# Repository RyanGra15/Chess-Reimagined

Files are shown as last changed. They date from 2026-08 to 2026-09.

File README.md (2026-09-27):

# Chess-Reimagined

An electronic chess board, that you can play (and lose) against 

## Features

* 64 Hall effect sensors to detect the position of the chess pieces
* LEDs matrix to indicate moves
* 0.96 inch OLED screen
* 3D printed board housing

## How It Works

The board uses Hall effect sensors underneath each square to detect whether a chess piece is present. Each chess piece will have a magnet embedded into its base, allowing the sensor underneath it to detect that a piece is present. Then, the software will take this, and represent it as a 64 bit string, with each bit signifying if there is a piece on the corresponding square. 

By backtracking through prior positions, all the way to the starting position, the ESP32 will be able to determine where each piece is. Then over Wifi, it will call the Stockfish API, get the best move, convert it back to the 64 bit string, and send it back to the Arduino. 

The Arduino will then control the LEDs underneath the board. The two squares involved in the move will light up, showing the player which piece to move and where to move it.

## Electronics

I am using multiplexing-esque approach for both the Hall effect sensors and the LEDs. By feeding 5V to a specified row, and making a specified column GND, I can choose to give power to a specific part. This allows me to control many signals without needing a separate connection for every single component. This keeps the circuit relatively simple and reduces the number of connections needed.

The main electronics are:

* Arduino Mega 2560
* ESP32
* Hall effect sensors
* LEDs
* S8550 PNP transistors
* Resistors
* Magnets
* Wires

The PCB is shown below, along with the schematic and routing diagrams: 













## CAD Model

The board housing will be 3D printed using PLA+. I chose PLA+ because it is cost efficient and is available in many different colors. The board will use a light grey and cold white colour scheme. 





The squares on the chess board have a hole in which the LED can be slotted into, along with a separate inset, wherein a extremely weak magnet can be placed, so that the chess pieces do not repel or attract each other, and instead they attract to the magnets embedded in the base of each square. This also has the added upside that you can flip the board upside down (if that is more your style ;)). See image below:



The chess pieces are also designed digitally and 3D printed, with some inspiration taken from previous chess related projects. 



The different parts will be attached together using hopes, dreams, and a lot of super glue.

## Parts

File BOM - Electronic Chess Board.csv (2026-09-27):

Item Name | Qty | Price (total) (EUR) | Price (total) (USD) | Item link | Notes
A3144EUA-T-JSM | 64 | € 6.96 | $8.07 | A3144EUA-T-JSM | Switches (Solid State) | JSMSEMI | LCSC | Must order a multiple of 5
5mm White Flat Top LED | 64 | € 6.04 | $7.01 | Amazon.com: CHANZON 100 pcs 5mm White Flat Top LED Diode Lights (DC 3V 20mA) | (Clear Transparent Lens) Bright Lighting Bulb Lamps Electronics Components Indicator Light Emitting Diodes DIY PCB Arduino : Industrial & Scientific | Preferably flat head LED
S8550 Transistor | 16 | € 1.32 | $1.53 | S8550 | Single Bipolar Transistors | JSMSEMI | LCSC | Must order a multiple of 100
20pcs 40P 2.54mm Pitch Single Row Pin Header Strip | 1 | € 4.74 | $5.50 | HiLetgo 20pcs 40P 2.54mm Pitch Single Row Pin Header Strip 40Pin 2.54mm Pitch: Amazon.com: Industrial & Scientific
MF1/4W-1K±1%-ST52 | 17 | € 0.76 | $0.88 | MF1/4W-1K±1%-ST52 | Through Hole Resistors | VO | LCSC | Must order a minimum quantity of 100
2.2K ohm, Resistance Tolerance: ± 5% tolerance, Material: Carbon Film | 1 | € 3.45 | $4.00 | California JOS 2.2K Ohm Carbon Film Single Fixed Resistor 1/2 W (0.5 Watts) 5% Tolerance (40 Pack): Amazon.com: Industrial & Scientific
HS96L03W2C03 | 1 | € 2.04 | $2.37 | HS96L03W2C03 | LCD, OLED, Graphic | HS | LCSC
MFR0W4F1002A50 | 50 | € 0.81 | $0.94 | MFR0W4F1002A50 | Through Hole Resistors | UNI-ROYAL | LCSC | Must order a minimum quantit of 50
Arduino Mega 2560 | 1 | € 16.99 | $19.71 | ARCELI Mega-2560-R3 Board, Mega-2560 Development Board with USB Cable Compatible with Arduino IDE : Amazon.nl: Electronics & Photo
ESP32 Devkit V1 | 1 | € 8.69 | $10.08 | JZK ESP-32S ESP32 Development Board 2.4GHz WiFi + Bluetooth Dual Mode Module Antenna Module with Ultra Low Power : Amazon.nl: Electronics & Photo
Solid Core 22 AWG Wire | 1 | € 19.99 | $23.19 | TUOFENG 22 awg solid wire - solid wire set - 6 different colored 9m spools, 22 gauge jumper wire - connection cable set : Amazon.nl: DIY & Tools
PLA Filament 1.75mm 1KG, White | 1 | € 13.99 | $16.23 | https://www.amazon.nl/-/en/eSUN-Filament-1-75mm-Printer-White/dp/B0CR1CS3K8
PLA Filament 1.75mm 1KG, Grey | 1 | € 13.99 | $16.23 | eSUN PLA Filament 1.75mm, PLA Base 3D Printer Filament 1kg White | Size accuracy +/- 0.02 mm. Smooth and fast printing without clogging. Premium material for FDM 3D printers. : Amazon.nl: Business, Industry & Science
USB C Power Recepticle | 1 | € 2.00 | $2.32 | 4 10pcs 2 pin type c extension cables transparent flat plug - Temu Netherlands
8mmx3mm Neodimium magnets | 32 | € 6.62 | $7.68 | refrigerator magnets 8x3mm magnet n35 magnetic round magnets - Temu Netherlands
1.5mm Self-Adhesive Magnets | 64 | € 1.53 | $1.77 | round self magnetic strip set made - Temu Netherlands
Total Price (USD): | $127.51

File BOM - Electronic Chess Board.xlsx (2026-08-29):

Item Name | Qty | Price (total) (EUR) | Price (total) (USD) | Item link | Notes
A3144EUA-T-JSM | 64 | €6.96 | $8.07 | A3144EUA-T-JSM | Switches (Solid State) | JSMSEMI | LCSC (https://www.lcsc.com/product-detail/C18188954.html) | Must order a multiple of 5
5mm White Flat Top LED | 64 | €6.04 | $7.01 | Amazon.com: CHANZON 100 pcs 5mm White Flat Top LED Diode Lights (DC 3V 20mA) | (Clear Transparent Lens) Bright Lighting Bulb Lamps Electronics Components Indicator Light Emitting Diodes DIY PCB Arduino : Industrial & Scientific (https://www.amazon.com/CHANZON-White-Flat-Diode-Lights/dp/B01BUVHSSE?cv_ct_cx=led%2Bkit%2Bflat%2Bhead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) | Preferably flat head LED
S8550 Transistor | 16 | €1.32 | $1.53 | S8550 | Single Bipolar Transistors | JSMSEMI | LCSC (https://www.lcsc.com/product-detail/C2931493.html) | Must order a multiple of 100
20pcs 40P 2.54mm Pitch Single Row Pin Header Strip | 1 | €4.74 | $5.50 | HiLetgo 20pcs 40P 2.54mm Pitch Single Row Pin Header Strip 40Pin 2.54mm Pitch: Amazon.com: Industrial & Scientific (https://www.amazon.com/HiLetgo-20pcs-2-54mm-Single-Header/dp/B07R5QDL8D)
MF1/4W-1K±1%-ST52 | 17 | €0.76 | $0.88 | MF1/4W-1K±1%-ST52 | Through Hole Resistors | VO | LCSC (https://www.lcsc.com/product-detail/C2903245.html?s_z=n_q_t_1k%2520resistor) | Must order a minimum quantity of 100
2.2K ohm, Resistance Tolerance: ± 5% tolerance, Material: Carbon Film | 1 | €3.45 | $4.00 | California JOS 2.2K Ohm Carbon Film Single Fixed Resistor 1/2 W (0.5 Watts) 5% Tolerance (40 Pack): Amazon.com: Industrial & Scientific (https://www.amazon.com/California-JOS-Carbon-Resistor-Tolerance/dp/B0BR699G4V)
HS96L03W2C03 | 1 | €2.04 | $2.37 | HS96L03W2C03 | LCD, OLED, Graphic | HS | LCSC (https://www.lcsc.com/product-detail/C5248080.html)
MFR0W4F1002A50 | 50 | €0.81 | $0.94 | MFR0W4F1002A50 | Through Hole Resistors | UNI-ROYAL | LCSC (https://www.lcsc.com/product-detail/C57436.html?s_z=n_q_t_10k%2520resistor) | Must order a minimum quantit of 50
Arduino Mega 2560 | 1 | €16.99 | $19.71 | ARCELI Mega-2560-R3 Board, Mega-2560 Development Board with USB Cable Compatible with Arduino IDE : Amazon.nl: Electronics & Photo (https://www.amazon.nl/-/en/ARCELI-Mega-2560-R3-Mega-2560-Development-Compatible/dp/B0CLVGDHCL)
ESP32 Devkit V1 | 1 | €8.69 | $10.08 | JZK ESP-32S ESP32 Development Board 2.4GHz WiFi + Bluetooth Dual Mode Module Antenna Module with Ultra Low Power : Amazon.nl: Electronics & Photo (https://www.amazon.nl/-/en/JZK-ESP-32S-Development-Bluetooth-Antenna/dp/B071JR9WS9)
Solid Core 22 AWG Wire | 1 | €19.99 | $23.19 | TUOFENG 22 awg solid wire - solid wire set - 6 different colored 9m spools, 22 gauge jumper wire - connection cable set : Amazon.nl: DIY & Tools (https://www.amazon.nl/-/en/TUOFENG-awg-solid-wire-connection/dp/B07V5FVSYL)
PLA Filament 1.75mm 1KG, White | 1 | €13.99 | $16.23 | https://www.amazon.nl/-/en/eSUN-Filament-1-75mm-Printer-White/dp/B0CR1CS3K8
PLA Filament 1.75mm 1KG, Grey | 1 | €13.99 | $16.23 | eSUN PLA Filament 1.75mm, PLA Base 3D Printer Filament 1kg White | Size accuracy +/- 0.02 mm. Smooth and fast printing without clogging. Premium material for FDM 3D printers. : Amazon.nl: Business, Industry & Science (https://www.amazon.nl/-/en/eSUN-Filament-1-75mm-Printer-White/dp/B0CR1BN5XB)
USB C Power Recepticle | 1 | €2.00 | $2.32 | 4 10pcs 2 pin type c extension cables transparent flat plug - Temu Netherlands (https://www.temu.com/nl-en/4-10pcs-2-pin-type-c-extension-cables-transparent-flat-plug-with-led-indicator-light--relief-cord-protector-solderable-female-type-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)
8mmx3mm Neodimium magnets | 32 | €6.62 | $7.68 | refrigerator magnets 8x3mm magnet n35 magnetic round magnets - Temu Netherlands (https://www.temu.com/nl-en/refrigerator-magnets-8x3mm-magnet-n35-magnetic-round-magnets--for-home-kitchen-office-g-605991982708116.html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)
1.5mm Self-Adhesive Magnets | 64 | €1.53 | $1.77 | round self magnetic strip set made - Temu Netherlands (https://www.temu.com/nl-en/-round-self--magnetic-strip-set-made-of-synthetic-rubber-flexible-and--multi-purpose-magnetic-strips-suitable-for-crafts-refrigerat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)
Total Price (USD): | $127.51

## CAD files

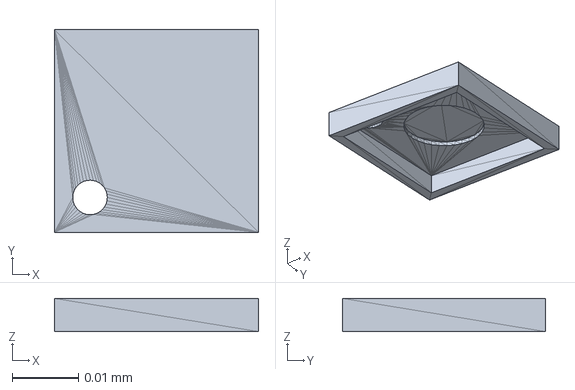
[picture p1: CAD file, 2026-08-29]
CAD/Chess Squares V4.step
0.0307 x 0.0305 x 0.005 mm

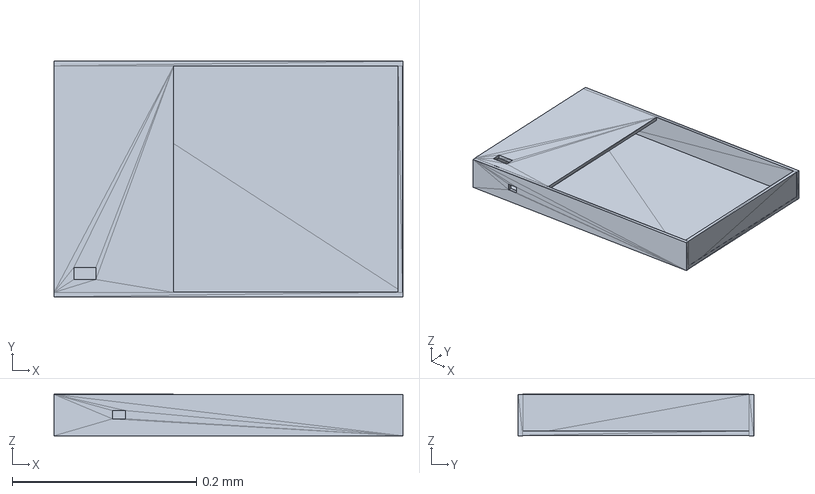
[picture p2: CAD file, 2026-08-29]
CAD/Chess Board V2.step
0.379 x 0.256 x 0.0452 mm
STEP translator 7.5 1.1
STEP translator 7.5 1.2
STEP translator 7.5 1.3
STEP translator 7.5 1.4
STEP translator 7.5 1.5
STEP translator 7.5 1.6

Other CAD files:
CAD/Chess Pieces V2 - 4mm - Full.step

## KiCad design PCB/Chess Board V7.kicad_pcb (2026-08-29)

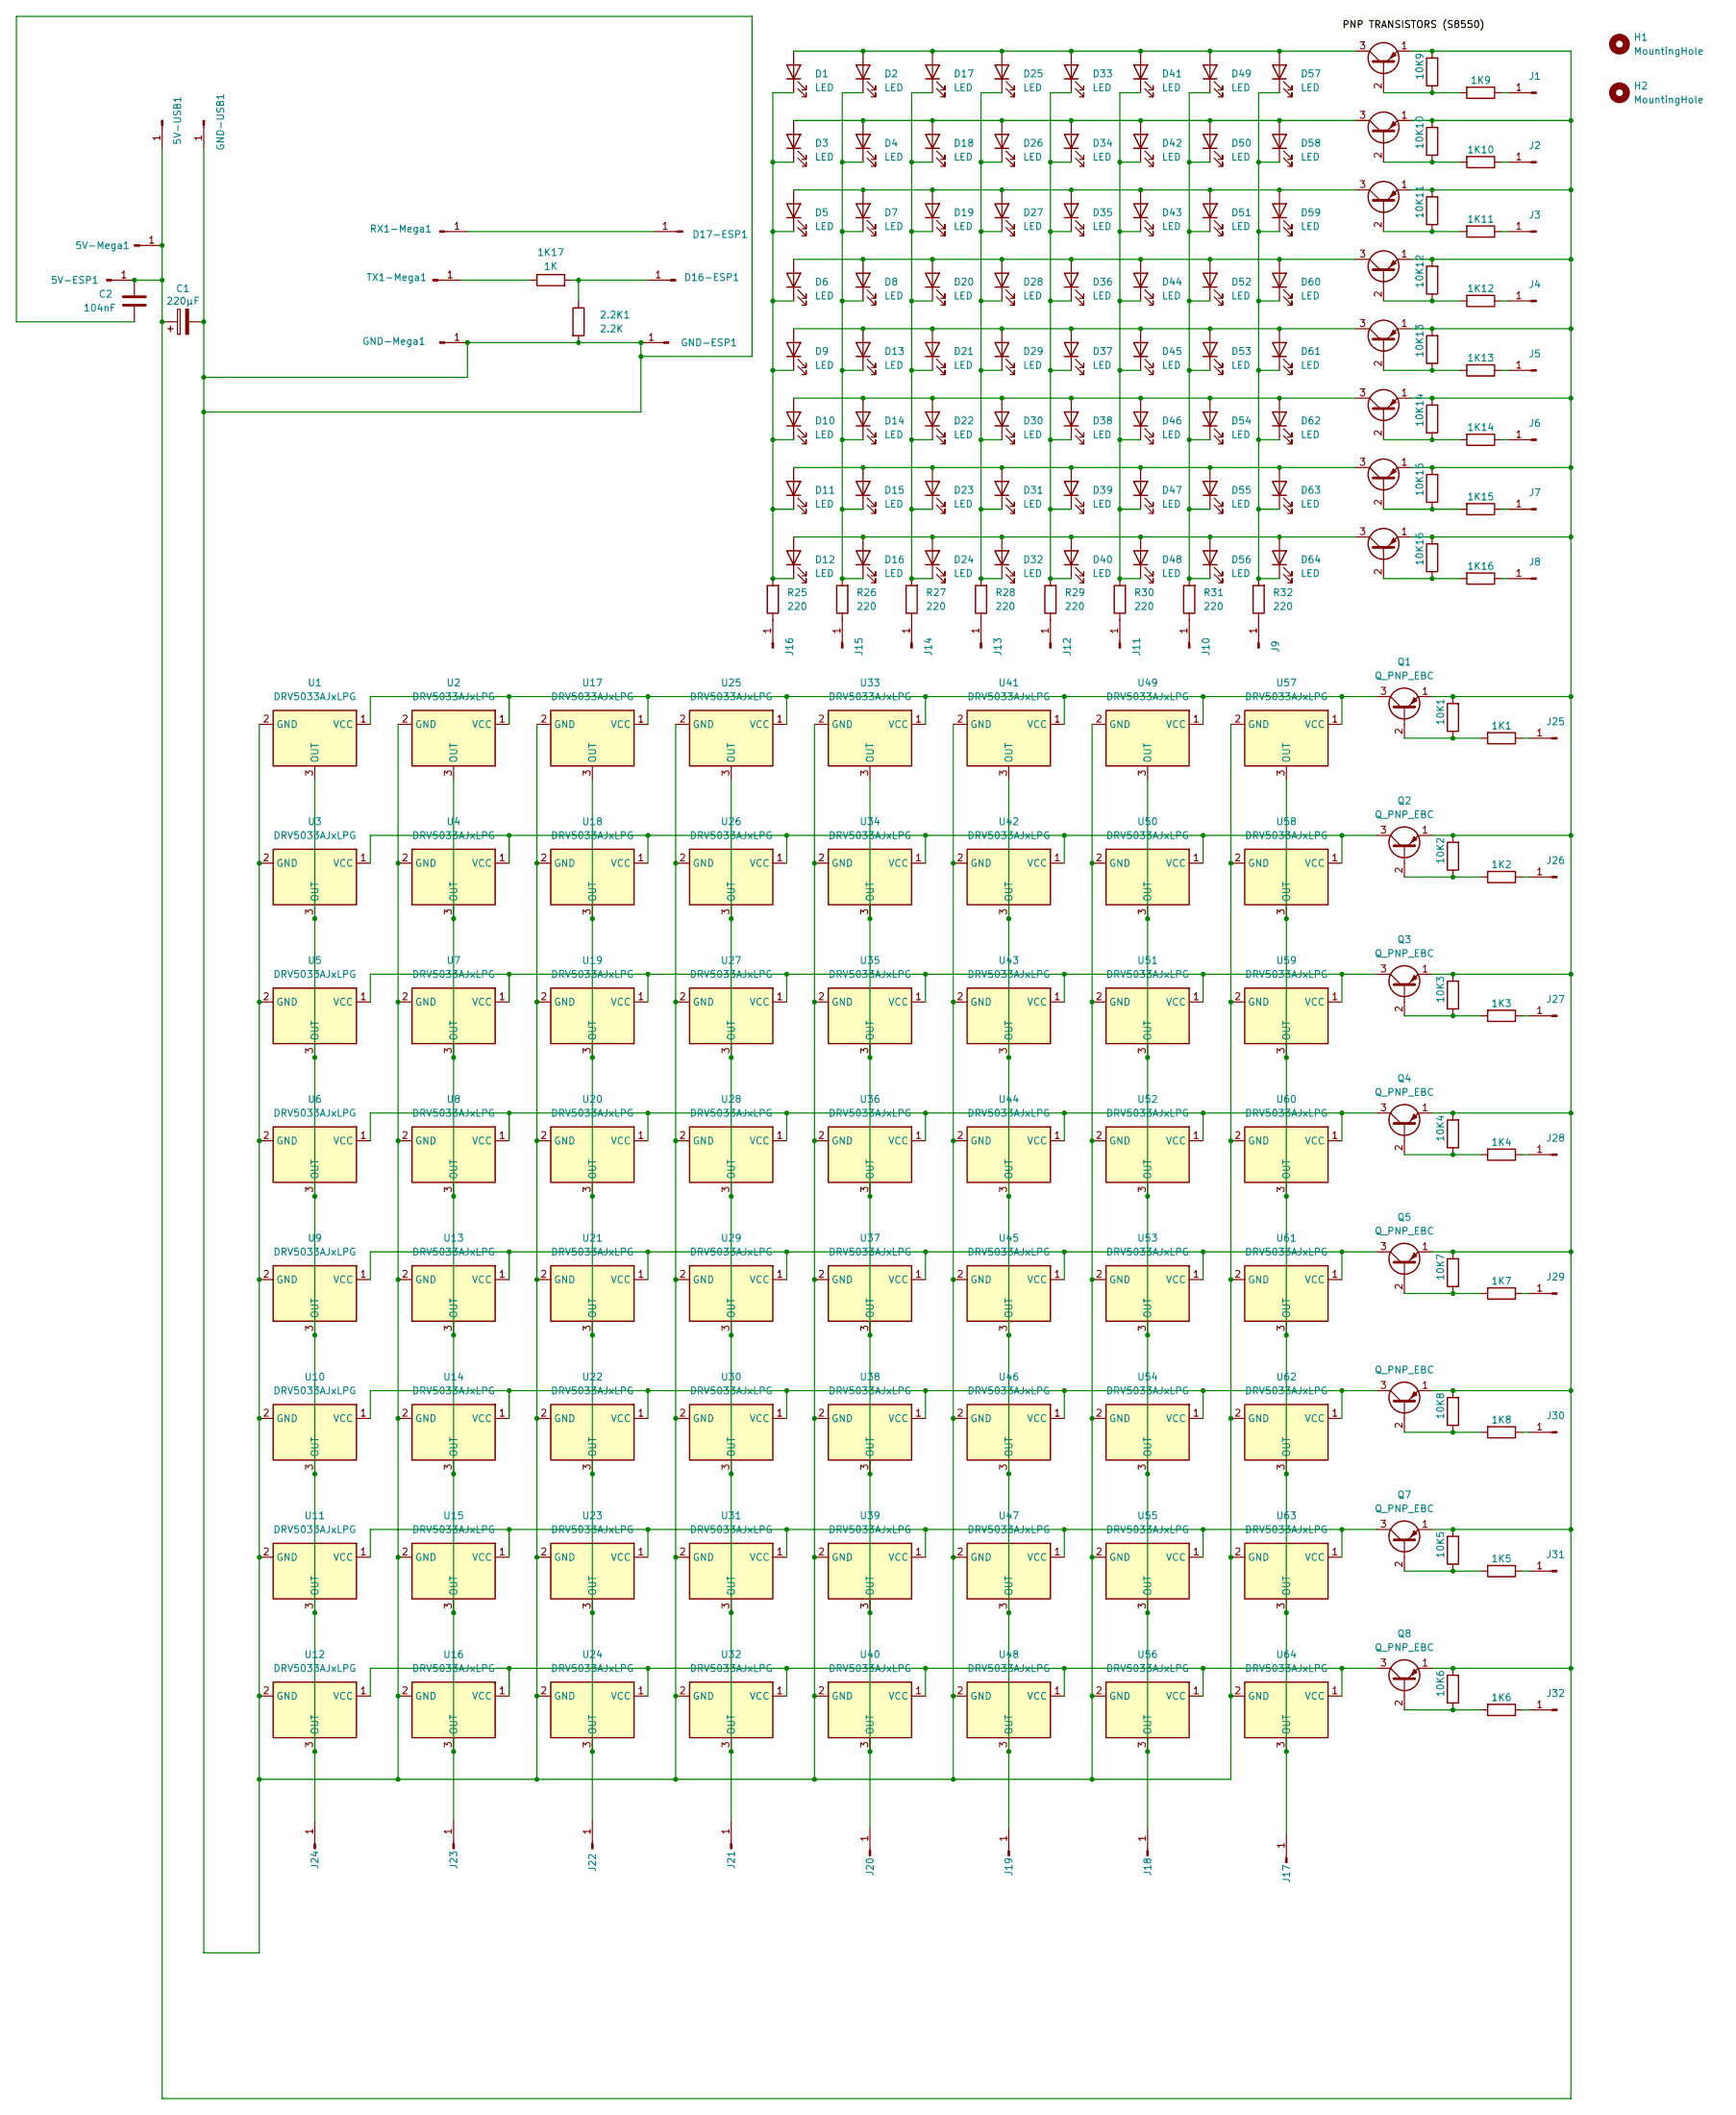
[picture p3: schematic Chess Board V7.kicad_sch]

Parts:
1K1, 1K2, 1K3, 1K4, 1K5, 1K6, 1K7, 1K8, 1K9, 1K10, 1K11, 1K12, 1K13, 1K14, 1K15, 1K16, 1K17: 1K; R_Axial_DIN0204_L3.6mm_D1.6mm_P7.62mm_Horizontal
2.2K1: 2.2K; R_Axial_DIN0204_L3.6mm_D1.6mm_P7.62mm_Horizontal
5V-ESP1, 5V-Mega1, 5V-USB1: Conn_01x01_Pin; PinHeader_1x01_P2.54mm_Vertical
10K1, 10K2, 10K3, 10K4, 10K5, 10K6, 10K7, 10K8, 10K9, 10K10, 10K11, 10K12, 10K13, 10K14, 10K15, 10K16: 10K; R_Axial_DIN0204_L3.6mm_D1.6mm_P7.62mm_Horizontal
C1: 220µF; CP_Radial_D6.3mm_P2.50mm
C2: 104nF; C_Disc_D5.0mm_W2.5mm_P2.50mm
D1, D2, D3, D4, D5, D6, D7, D8, D9, D10, D11, D12, D13, D14, D15, D16, D17, D18, D19, D20, D21, D22, D23, D24, D25, D26, D27, D28, D29, D30, D31, D32, D33, D34, D35, D36, D37, D38, D39, D40, D41, D42, D43, D44, D45, D46, D47, D48, D49, D50, D51, D52, D53, D54, D55, D56, D57, D58, D59, D60, D61, D62, D63, D64: LED; LED_D3.0mm_FlatTop
D16-ESP1, D17-ESP1: Conn_01x01_Pin; PinHeader_1x01_P2.54mm_Vertical
GND-ESP1: Conn_01x01_Pin; PinHeader_1x01_P2.54mm_Vertical
GND-Mega1: Conn_01x01_Pin; PinHeader_1x01_P2.54mm_Vertical
GND-USB1: Conn_01x01_Pin; PinHeader_1x01_P2.54mm_Vertical
H1, H2: MountingHole; MountingHole_2.7mm
J1, J2, J3, J4, J5, J6, J7, J8, J9, J10, J11, J12, J13, J14, J15, J16, J17, J18, J19, J20, J21, J22, J23, J24, J25, J26, J27, J28, J29, J30, J31, J32: Conn_01x01_Pin; PinHeader_1x01_P2.54mm_Vertical
Q1, Q2, Q3, Q4, Q5, Q6, Q7, Q8, Q9, Q10, Q11, Q12, Q13, Q14, Q15, Q16: Q_PNP_EBC; TO-92_Inline_Wide
R25, R26, R27, R28, R29, R30, R31, R32: 220; R_Axial_DIN0204_L3.6mm_D1.6mm_P7.62mm_Horizontal
RX1-Mega1: Conn_01x01_Pin; PinHeader_1x01_P2.54mm_Vertical
TX1-Mega1: Conn_01x01_Pin; PinHeader_1x01_P2.54mm_Vertical
U1, U2, U3, U4, U5, U6, U7, U8, U9, U10, U11, U12, U13, U14, U15, U16, U17, U18, U19, U20, U21, U22, U23, U24, U25, U26, U27, U28, U29, U30, U31, U32, U33, U34, U35, U36, U37, U38, U39, U40, U41, U42, U43, U44, U45, U46, U47, U48, U49, U50, U51, U52, U53, U54, U55, U56, U57, U58, U59, U60, U61, U62, U63, U64: DRV5033AJxLPG; TO-92_Inline_Wide

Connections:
unnamed 0: 5V-ESP1.1, 5V-Mega1.1, 5V-USB1.1, 10K1.2, 10K2.2, 10K3.2, 10K4.2, 10K5.2, 10K6.2, 10K7.2, 10K8.2, 10K9.2, 10K10.2, 10K11.2, 10K12.2, 10K13.2, 10K14.2, 10K15.2, 10K16.2, C1.1, C2.1, Q1.1 (E), Q2.1 (E), Q3.1 (E), Q4.1 (E), Q5.1 (E), Q6.1 (E), Q7.1 (E), Q8.1 (E), Q9.1 (E), Q10.1 (E), Q11.1 (E), Q12.1 (E), Q13.1 (E), Q14.1 (E), Q15.1 (E), Q16.1 (E); also elsewhere on the board
unnamed: D1.2 (A), D2.2 (A), D17.2 (A), D25.2 (A), D33.2 (A), D41.2 (A), D49.2 (A), D57.2 (A), Q9.3 (C)
unnamed: D1.1 (K), D3.1 (K), D5.1 (K), D6.1 (K), D9.1 (K), D10.1 (K), D11.1 (K), D12.1 (K), R25.2
unnamed: D10.2 (A), D14.2 (A), D22.2 (A), D30.2 (A), D38.2 (A), D46.2 (A), D54.2 (A), D62.2 (A), Q14.3 (C)
unnamed: D11.2 (A), D15.2 (A), D23.2 (A), D31.2 (A), D39.2 (A), D47.2 (A), D55.2 (A), D63.2 (A), Q15.3 (C)
unnamed: D12.2 (A), D16.2 (A), D24.2 (A), D32.2 (A), D40.2 (A), D48.2 (A), D56.2 (A), D64.2 (A), Q16.3 (C)
unnamed: D9.2 (A), D13.2 (A), D21.2 (A), D29.2 (A), D37.2 (A), D45.2 (A), D53.2 (A), D61.2 (A), Q13.3 (C)
unnamed: D2.1 (K), D4.1 (K), D7.1 (K), D8.1 (K), D13.1 (K), D14.1 (K), D15.1 (K), D16.1 (K), R26.2
unnamed: 1K17.2, 2.2K1.1, D16-ESP1.1
unnamed: D17-ESP1.1, RX1-Mega1.1
unnamed: D17.1 (K), D18.1 (K), D19.1 (K), D20.1 (K), D21.1 (K), D22.1 (K), D23.1 (K), D24.1 (K), R27.2
unnamed: D3.2 (A), D4.2 (A), D18.2 (A), D26.2 (A), D34.2 (A), D42.2 (A), D50.2 (A), D58.2 (A), Q10.3 (C)
unnamed: D5.2 (A), D7.2 (A), D19.2 (A), D27.2 (A), D35.2 (A), D43.2 (A), D51.2 (A), D59.2 (A), Q11.3 (C)
unnamed: D6.2 (A), D8.2 (A), D20.2 (A), D28.2 (A), D36.2 (A), D44.2 (A), D52.2 (A), D60.2 (A), Q12.3 (C)
unnamed: D25.1 (K), D26.1 (K), D27.1 (K), D28.1 (K), D29.1 (K), D30.1 (K), D31.1 (K), D32.1 (K), R28.2
unnamed: D33.1 (K), D34.1 (K), D35.1 (K), D36.1 (K), D37.1 (K), D38.1 (K), D39.1 (K), D40.1 (K), R29.2
unnamed: D41.1 (K), D42.1 (K), D43.1 (K), D44.1 (K), D45.1 (K), D46.1 (K), D47.1 (K), D48.1 (K), R30.2
unnamed: D49.1 (K), D50.1 (K), D51.1 (K), D52.1 (K), D53.1 (K), D54.1 (K), D55.1 (K), D56.1 (K), R31.2
unnamed: D57.1 (K), D58.1 (K), D59.1 (K), D60.1 (K), D61.1 (K), D62.1 (K), D63.1 (K), D64.1 (K), R32.2
unnamed 19: 2.2K1.2, C1.2, C2.2, GND-ESP1.1, GND-Mega1.1, GND-USB1.1, U1.2 (GND), U2.2 (GND), U3.2 (GND), U4.2 (GND), U5.2 (GND), U6.2 (GND), U7.2 (GND), U8.2 (GND), U9.2 (GND), U10.2 (GND), U11.2 (GND), U12.2 (GND), U13.2 (GND), U14.2 (GND), U15.2 (GND), U16.2 (GND), U17.2 (GND), U18.2 (GND), U19.2 (GND), U20.2 (GND), U21.2 (GND), U22.2 (GND), U23.2 (GND), U24.2 (GND), U25.2 (GND), U26.2 (GND), U27.2 (GND), U28.2 (GND), U29.2 (GND), U30.2 (GND), U31.2 (GND), U32.2 (GND), U33.2 (GND), U34.2 (GND), U35.2 (GND), U36.2 (GND), U37.2 (GND), U38.2 (GND), U39.2 (GND), U40.2 (GND), U41.2 (GND), U42.2 (GND), U43.2 (GND), U44.2 (GND), U45.2 (GND), U46.2 (GND), U47.2 (GND), U48.2 (GND), U49.2 (GND), U50.2 (GND), U51.2 (GND), U52.2 (GND), U53.2 (GND), U54.2 (GND), U55.2 (GND), U56.2 (GND), U57.2 (GND), U58.2 (GND), U59.2 (GND), U60.2 (GND), U61.2 (GND), U62.2 (GND), U63.2 (GND), U64.2 (GND); also elsewhere on the board
unnamed: 1K9.1, J1.1
unnamed: 1K10.1, J2.1
unnamed: 1K11.1, J3.1
unnamed: 1K12.1, J4.1
unnamed: 1K13.1, J5.1
unnamed: 1K14.1, J6.1
unnamed: 1K15.1, J7.1
unnamed: 1K16.1, J8.1
unnamed: J9.1, R32.1
unnamed: J10.1, R31.1
unnamed: J11.1, R30.1
unnamed: J12.1, R29.1
unnamed: J13.1, R28.1
unnamed: J14.1, R27.1
unnamed: J15.1, R26.1
unnamed: J16.1, R25.1
unnamed: J17.1, U57.3 (OUT), U58.3 (OUT), U59.3 (OUT), U60.3 (OUT), U61.3 (OUT), U62.3 (OUT), U63.3 (OUT), U64.3 (OUT)
unnamed: J18.1, U49.3 (OUT), U50.3 (OUT), U51.3 (OUT), U52.3 (OUT), U53.3 (OUT), U54.3 (OUT), U55.3 (OUT), U56.3 (OUT)
unnamed: J19.1, U41.3 (OUT), U42.3 (OUT), U43.3 (OUT), U44.3 (OUT), U45.3 (OUT), U46.3 (OUT), U47.3 (OUT), U48.3 (OUT)
unnamed: J20.1, U33.3 (OUT), U34.3 (OUT), U35.3 (OUT), U36.3 (OUT), U37.3 (OUT), U38.3 (OUT), U39.3 (OUT), U40.3 (OUT)
unnamed: J21.1, U25.3 (OUT), U26.3 (OUT), U27.3 (OUT), U28.3 (OUT), U29.3 (OUT), U30.3 (OUT), U31.3 (OUT), U32.3 (OUT)
unnamed: J22.1, U17.3 (OUT), U18.3 (OUT), U19.3 (OUT), U20.3 (OUT), U21.3 (OUT), U22.3 (OUT), U23.3 (OUT), U24.3 (OUT)
unnamed: J23.1, U2.3 (OUT), U4.3 (OUT), U7.3 (OUT), U8.3 (OUT), U13.3 (OUT), U14.3 (OUT), U15.3 (OUT), U16.3 (OUT)
unnamed: J24.1, U1.3 (OUT), U3.3 (OUT), U5.3 (OUT), U6.3 (OUT), U9.3 (OUT), U10.3 (OUT), U11.3 (OUT), U12.3 (OUT)
unnamed: 1K1.1, J25.1
unnamed: 1K2.1, J26.1
unnamed: 1K3.1, J27.1
unnamed: 1K4.1, J28.1
unnamed: 1K7.1, J29.1
unnamed: 1K8.1, J30.1
unnamed: 1K5.1, J31.1
unnamed: 1K6.1, J32.1
unnamed: 1K1.2, 10K1.1, Q1.2 (B)
unnamed: Q1.3 (C), U1.1 (VCC), U2.1 (VCC), U17.1 (VCC), U25.1 (VCC), U33.1 (VCC), U41.1 (VCC), U49.1 (VCC), U57.1 (VCC)
unnamed: 1K2.2, 10K2.1, Q2.2 (B)
unnamed: Q2.3 (C), U3.1 (VCC), U4.1 (VCC), U18.1 (VCC), U26.1 (VCC), U34.1 (VCC), U42.1 (VCC), U50.1 (VCC), U58.1 (VCC)
unnamed: 1K3.2, 10K3.1, Q3.2 (B)
unnamed: Q3.3 (C), U5.1 (VCC), U7.1 (VCC), U19.1 (VCC), U27.1 (VCC), U35.1 (VCC), U43.1 (VCC), U51.1 (VCC), U59.1 (VCC)
unnamed: 1K4.2, 10K4.1, Q4.2 (B)
unnamed: Q4.3 (C), U6.1 (VCC), U8.1 (VCC), U20.1 (VCC), U28.1 (VCC), U36.1 (VCC), U44.1 (VCC), U52.1 (VCC), U60.1 (VCC)
unnamed: 1K7.2, 10K7.1, Q5.2 (B)
unnamed: Q5.3 (C), U9.1 (VCC), U13.1 (VCC), U21.1 (VCC), U29.1 (VCC), U37.1 (VCC), U45.1 (VCC), U53.1 (VCC), U61.1 (VCC)
unnamed: 1K8.2, 10K8.1, Q6.2 (B)
unnamed: Q6.3 (C), U10.1 (VCC), U14.1 (VCC), U22.1 (VCC), U30.1 (VCC), U38.1 (VCC), U46.1 (VCC), U54.1 (VCC), U62.1 (VCC)
unnamed: 1K5.2, 10K5.1, Q7.2 (B)
unnamed: Q7.3 (C), U11.1 (VCC), U15.1 (VCC), U23.1 (VCC), U31.1 (VCC), U39.1 (VCC), U47.1 (VCC), U55.1 (VCC), U63.1 (VCC)
unnamed: 1K6.2, 10K6.1, Q8.2 (B)
unnamed: Q8.3 (C), U12.1 (VCC), U16.1 (VCC), U24.1 (VCC), U32.1 (VCC), U40.1 (VCC), U48.1 (VCC), U56.1 (VCC), U64.1 (VCC)
unnamed: 1K9.2, 10K9.1, Q9.2 (B)
unnamed: 1K10.2, 10K10.1, Q10.2 (B)
unnamed: 1K11.2, 10K11.1, Q11.2 (B)
unnamed: 1K12.2, 10K12.1, Q12.2 (B)
unnamed: 1K13.2, 10K13.1, Q13.2 (B)
unnamed: 1K14.2, 10K14.1, Q14.2 (B)
unnamed: 1K15.2, 10K15.1, Q15.2 (B)
unnamed: 1K16.2, 10K16.1, Q16.2 (B)
unnamed: 1K17.1, TX1-Mega1.1

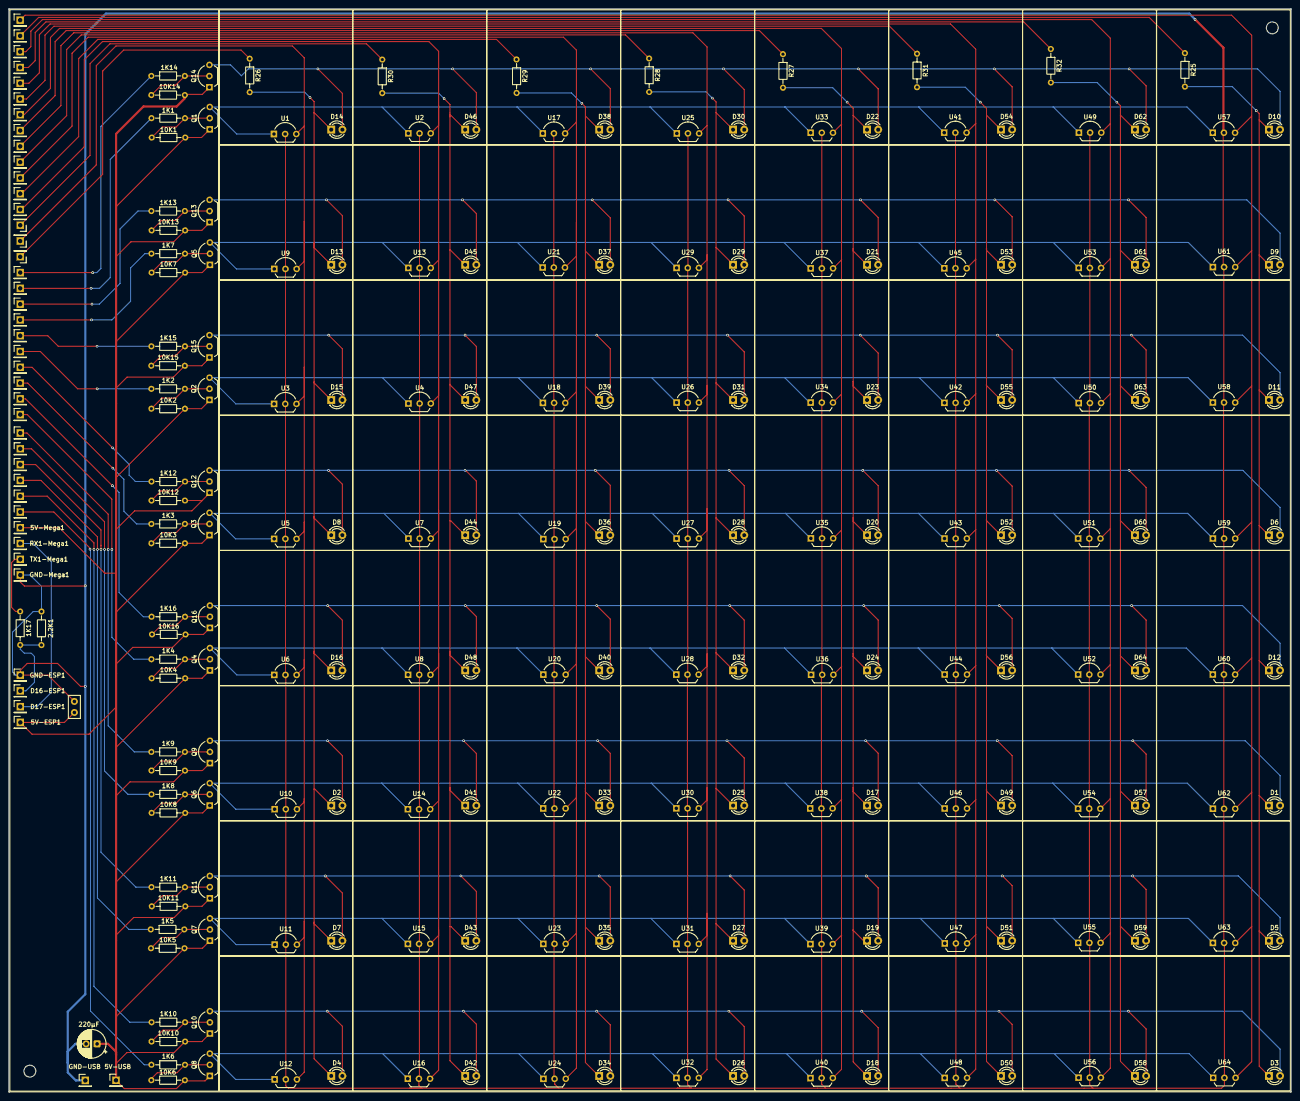
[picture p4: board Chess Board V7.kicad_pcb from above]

Board: 2 copper layers, 291.5 x 246.2 mm, 232 parts (0 on the bottom side), 77 nets.

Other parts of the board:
5V-USB: Conn_01x01_Pin; PinHeader_1x01_P2.54mm_Vertical
220µF: 220µF; CP_Radial_D6.3mm_P2.50mm
GND-USB: Conn_01x01_Pin; PinHeader_1x01_P2.54mm_Vertical

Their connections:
unnamed 0: 5V-USB.1, 220µF.1; also elsewhere on the board
unnamed 19: 220µF.2, GND-USB.1; also elsewhere on the board

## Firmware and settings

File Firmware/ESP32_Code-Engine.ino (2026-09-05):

#include <WiFi.h>
#include <HTTPClient.h>
#include <ArduinoJson.h>
#include <WiFiClientSecure.h>

const char* wifi = "wifi_name";
const char* wifi_password = "wifi_password";

HardwareSerial MegaSerial(2);

String line = "";

char board[8][8] = {
  {'r','n','b','q','k','b','n','r'},
  {'p','p','p','p','p','p','p','p'},
  {' ',' ',' ',' ',' ',' ',' ',' '},
  {' ',' ',' ',' ',' ',' ',' ',' '},
  {' ',' ',' ',' ',' ',' ',' ',' '},
  {' ',' ',' ',' ',' ',' ',' ',' '},
  {'P','P','P','P','P','P','P','P'},
  {'R','N','B','Q','K','B','N','R'}
};

bool whiteTurn = true;

bool whiteCastleKing = true;
bool whiteCastleQueen = true;
bool blackCastleKing = true;
bool blackCastleQueen = true;

String enPassant = "-";

int halfmove = 0;
int fullmove = 1;


void setup() {

  Serial.begin(115200);

  MegaSerial.begin(
    115200,
    SERIAL_8N1,
    16,
    17
  );

  WiFi.begin(wifi, wifi_password);

  Serial.print("WiFi");

  while (WiFi.status() != WL_CONNECTED) {

    delay(500);
    Serial.print(".");
  }

  Serial.println();
  Serial.println("Connected");
  Serial.println(WiFi.localIP());

  Serial.println("Chess ESP32 ready");
}


void loop() {

  while (MegaSerial.available()) {

    char c = MegaSerial.read();

    if (c == '\n') {

      line.trim();

      if (line.startsWith("MOVE:")) {

        String move = line.substring(5);
        move.trim();

        Serial.print("Received move: ");
        Serial.println(move);

        if (makeMove(move)) {

          String fen = makeFEN();

          Serial.print("FEN: ");
          Serial.println(fen);

          String bestMove = getMove(fen);

          if (bestMove != "") {

            Serial.print("Engine move: ");
            Serial.println(bestMove);

            MegaSerial.print("LIGHT: ");

            MegaSerial.print(bestMove.substring(0, 2));
            MegaSerial.print(",");
            MegaSerial.println(bestMove.substring(2, 4));

            makeEngineMove(bestMove);
          }
        }
      }

      line = "";
    }
    else {

      line += c;
    }
  }
}


bool makeMove(String move) {

  move.trim();

  int arrow = move.indexOf("->");

  if (arrow == -1) {

    Serial.println("Bad move format");
    return false;
  }

  String from = move.substring(0, arrow);
  String to = move.substring(arrow + 2);

  from.trim();
  to.trim();

  from.toLowerCase();
  to.toLowerCase();

  if (from.length() != 2 || to.length() != 2) {

    Serial.println("Bad square");
    return false;
  }

  int fromCol = from[0] - 'a';
  int fromRow = 8 - (from[1] - '0');

  int toCol = to[0] - 'a';
  int toRow = 8 - (to[1] - '0');

  if (
    fromCol < 0 || fromCol > 7 ||
    fromRow < 0 || fromRow > 7 ||
    toCol < 0 || toCol > 7 ||
    toRow < 0 || toRow > 7
  ) {

    Serial.println("Square outside board");
    return false;
  }

  char piece = board[fromRow][fromCol];
  char captured = board[toRow][toCol];

  if (piece == ' ') {

    Serial.println("No piece on source square");
    return false;
  }

  if (isWhite(piece) != whiteTurn) {

    Serial.println("Wrong side to move");
    return false;
  }

  if (
    (piece == 'P' || piece == 'p') &&
    captured == ' ' &&
    fromCol != toCol
  ) {

    if (toRow == 2 || toRow == 5) {

      int captureRow;

      if (piece == 'P')
        captureRow = toRow + 1;
      else
        captureRow = toRow - 1;

      if (
        captureRow >= 0 &&
        captureRow < 8 &&
        board[captureRow][toCol] != ' '
      ) {

        board[captureRow][toCol] = ' ';
      }
    }
  }

  updateCastling(piece, fromRow, fromCol);

  if (captured != ' ') {

    if (captured == 'R') {

      if (toRow == 7 && toCol == 0)
        whiteCastleQueen = false;

      if (toRow == 7 && toCol == 7)
        whiteCastleKing = false;
    }

    if (captured == 'r') {

      if (toRow == 0 && toCol == 0)
        blackCastleQueen = false;

      if (toRow == 0 && toCol == 7)
        blackCastleKing = false;
    }
  }

  board[toRow][toCol] = piece;
  board[fromRow][fromCol] = ' ';

  if (piece == 'P' && toRow == 0)
    board[toRow][toCol] = 'Q';

  if (piece == 'p' && toRow == 7)
    board[toRow][toCol] = 'q';

  enPassant = "-";

  if (piece == 'P' && fromRow == 6 && toRow == 4) {

    enPassant =
      String(char('a' + fromCol)) +
      String(3);
  }

  if (piece == 'p' && fromRow == 1 && toRow == 3) {

    enPassant =
      String(char('a' + fromCol)) +
      String(6);
  }

  if (piece == 'P' || piece == 'p' || captured != ' ')
    halfmove = 0;
  else
    halfmove++;

  if (!whiteTurn)
    fullmove++;

  whiteTurn = !whiteTurn;

  return true;
}


void updateCastling(char piece, int row, int col) {

  if (piece == 'K') {

    whiteCastleKing = false;
    whiteCastleQueen = false;

    if (row == 7 && col == 4) {

      if (board[7][7] == 'R' && board[7][6] == ' ') {

        board[7][5] = 'R';
        board[7][7] = ' ';
      }

      else if (board[7][0] == 'R' && board[7][1] == ' ') {

        board[7][3] = 'R';
        board[7][0] = ' ';
      }
    }
  }

  if (piece == 'k') {

    blackCastleKing = false;
    blackCastleQueen = false;

    if (row == 0 && col == 4) {

      if (board[0][7] == 'r' && board[0][6] == ' ') {

        board[0][5] = 'r';
        board[0][7] = ' ';
      }

      else if (board[0][0] == 'r' && board[0][1] == ' ') {

        board[0][3] = 'r';
        board[0][0] = ' ';
      }
    }
  }

  if (piece == 'R') {

    if (row == 7 && col == 0)
      whiteCastleQueen = false;

    if (row == 7 && col == 7)
      whiteCastleKing = false;
  }

  if (piece == 'r') {

    if (row == 0 && col == 0)
      blackCastleQueen = false;

    if (row == 0 && col == 7)
      blackCastleKing = false;
  }
}


String makeFEN() {

  String fen = "";

  for (int row = 0; row < 8; row++) {

    int empty = 0;

    for (int col = 0; col < 8; col++) {

      char piece = board[row][col];

      if (piece == ' ') {

        empty++;
      }
      else {

        if (empty > 0) {

          fen += String(empty);
          empty = 0;
        }

        fen += piece;
      }
    }

    if (empty > 0)
      fen += String(empty);

    if (row != 7)
      fen += "/";
  }

  fen += " ";

  if (whiteTurn)
    fen += "w";
  else
    fen += "b";

  fen += " ";

  String castle = "";

  if (whiteCastleKing)
    castle += "K";

  if (whiteCastleQueen)
    castle += "Q";

  if (blackCastleKing)
    castle += "k";

  if (blackCastleQueen)
    castle += "q";

  if (castle == "")
    castle = "-";

  fen += castle;

  fen += " ";
  fen += enPassant;

  fen += " ";
  fen += String(halfmove);

  fen += " ";
  fen += String(fullmove);

  return fen;
}


String getMove(String fen) {

  if (WiFi.status() != WL_CONNECTED) {

    Serial.println("WiFi lost");

    WiFi.begin(wifi, wifi_password);

    return "";
  }

  WiFiClientSecure client;

  client.setInsecure();

  HTTPClient http;

  String url =
    "https://stockfish.online/api/s/v2.php?fen=";

  url += urlencode(fen);
  url += "&depth=12";

  Serial.println("Sending to Stockfish...");

  if (!http.begin(client, url)) {

    Serial.println("HTTP begin failed");
    return "";
  }

  http.addHeader(
    "Accept",
    "application/json"
  );

  int status = http.GET();

  if (status != 200) {

    Serial.print("API error: ");
    Serial.println(status);

    http.end();

    return "";
  }

  String response = http.getString();

  http.end();

  Serial.print("API response: ");
  Serial.println(response);

  JsonDocument doc;

  DeserializationError error =
    deserializeJson(doc, response);

  if (error) {

    Serial.print("JSON error: ");
    Serial.println(error.c_str());

    return "";
  }

  bool success = doc["success"];

  if (!success) {

    Serial.println("Stockfish request failed");

    return "";
  }

  const char* best =
    doc["bestmove"];

  if (best == nullptr) {

    Serial.println("No bestmove received");

    return "";
  }

  String bestMove = String(best);

  Serial.print("Raw bestmove: ");
  Serial.println(bestMove);

  int firstSpace = bestMove.indexOf(' ');

  if (firstSpace == -1) {

    if (bestMove.length() >= 4)
      return bestMove.substring(0, 4);

    return "";
  }

  int secondSpace =
    bestMove.indexOf(' ', firstSpace + 1);

  if (secondSpace == -1) {

    return bestMove.substring(firstSpace + 1);
  }

  return bestMove.substring(
    firstSpace + 1,
    secondSpace
  );
}


void makeEngineMove(String move) {

  if (move.length() < 4)
    return;

  move.toLowerCase();

  int fromCol = move[0] - 'a';
  int fromRow = 8 - (move[1] - '0');

  int toCol = move[2] - 'a';
  int toRow = 8 - (move[3] - '0');

  if (
    fromCol < 0 || fromCol > 7 ||
    fromRow < 0 || fromRow > 7 ||
    toCol < 0 || toCol > 7 ||
    toRow < 0 || toRow > 7
  )
    return;

  char piece = board[fromRow][fromCol];

  if (piece == ' ')
    return;

  char captured = board[toRow][toCol];

  updateCastling(piece, fromRow, fromCol);

  if (captured == 'R') {

    if (toRow == 7 && toCol == 0)
      whiteCastleQueen = false;

    if (toRow == 7 && toCol == 7)
      whiteCastleKing = false;
  }

  if (captured == 'r') {

    if (toRow == 0 && toCol == 0)
      blackCastleQueen = false;

    if (toRow == 0 && toCol == 7)
      blackCastleKing = false;
  }

  board[toRow][toCol] = piece;
  board[fromRow][fromCol] = ' ';

  if (move.length() >= 5) {

    char promotion = move[4];

    if (piece == 'P') {

      if (promotion == 'q')
        board[toRow][toCol] = 'Q';

      if (promotion == 'r')
        board[toRow][toCol] = 'R';

      if (promotion == 'b')
        board[toRow][toCol] = 'B';

      if (promotion == 'n')
        board[toRow][toCol] = 'N';
    }

    if (piece == 'p') {

      if (promotion == 'q')
        board[toRow][toCol] = 'q';

      if (promotion == 'r')
        board[toRow][toCol] = 'r';

      if (promotion == 'b')
        board[toRow][toCol] = 'b';

      if (promotion == 'n')
        board[toRow][toCol] = 'n';
    }
  }

  if (piece == 'P' || piece == 'p' || captured != ' ')
    halfmove = 0;
  else
    halfmove++;

  if (!whiteTurn)
    fullmove++;

  enPassant = "-";

  if (piece == 'P' && fromRow == 6 && toRow == 4) {

    enPassant =
      String(char('a' + fromCol)) +
      String(3);
  }

  if (piece == 'p' && fromRow == 1 && toRow == 3) {

    enPassant =
      String(char('a' + fromCol)) +
      String(6);
  }

  whiteTurn = !whiteTurn;
}


bool isWhite(char piece) {

  return (
    piece == 'P' ||
    piece == 'N' ||
    piece == 'B' ||
    piece == 'R' ||
    piece == 'Q' ||
    piece == 'K'
  );
}


String urlencode(String text) {

  String result = "";

  const char* hex =
    "0123456789ABCDEF";

  for (int i = 0; i < text.length(); i++) {

    char c = text[i];

    if (
      (c >= 'a' && c <= 'z') ||
      (c >= 'A' && c <= 'Z') ||
      (c >= '0' && c <= '9') ||
      c == '-' ||
      c == '_' ||
      c == '.' ||
      c == '~'
    ) {

      result += c;
    }
    else {

      result += '%';

      result +=
        hex[(c >> 4) & 0x0F];

      result +=
        hex[c & 0x0F];
    }
  }

  return result;
}

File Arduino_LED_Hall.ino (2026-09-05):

#include <Arduino.h>

HardwareSerial ESPSerial(1);

const int hallRows[] = {22, 23, 24, 25, 26, 27, 28, 29};
const int hallCols[] = {30, 31, 32, 33, 34, 35, 36, 37};

const int ledRows[] = {38, 39, 40, 41, 42, 43, 44, 45};
const int ledCols[] = {46, 47, 48, 49, 50, 51, 52, 53};

int board[64] = {
  1, 1, 1, 1, 1, 1, 1, 1,
  1, 1, 1, 1, 1, 1, 1, 1,
  0, 0, 0, 0, 0, 0, 0, 0,
  0, 0, 0, 0, 0, 0, 0, 0,
  0, 0, 0, 0, 0, 0, 0, 0,
  0, 0, 0, 0, 0, 0, 0, 0,
  1, 1, 1, 1, 1, 1, 1, 1,
  1, 1, 1, 1, 1, 1, 1, 1
};

int oldBoard[64] = {0};

bool leds[8][8] = {false};

unsigned long lastLED = 0;
int ledDelay = 2;

int lifted = -1;
int placed = -1;

void setup() {
  ESPSerial.begin(115200);

  for(int i = 0;i<8;i++) {
    pinMode(hallRows[i], OUTPUT);
    digitalWrite(hallRows[i], LOW);

    pinMode(ledRows[i], OUTPUT);
    digitalWrite(ledRows[i], LOW);
  }

  for(int i = 0; i < 8; i++) {
    pinMode(hallCols[i], INPUT_PULLUP);

    pinMode(ledCols[i], OUTPUT);
    digitalWrite(ledCols[i], HIGH);
  }

  for(int i = 0;i<64;i++)
    oldBoard[i] = board[i];

  ESPSerial.println("MEGA STARTED");
}

void scanHall() {
  for(int row = 0; row<8; row++) {
    for(int x = 0;x<8;x++)
      digitalWrite(hallRows[x], LOW);

    digitalWrite(hallRows[row], HIGH);

    for(int col = 0;col<8;col++) {
      int a = digitalRead(hallCols[col]);

      delayMicroseconds(120);

      int b = digitalRead(hallCols[col]);

      int n = row * 8 + col;

      if(a == b) {
        if(a == LOW)
          board[n] = 1;
        else
          board[n] = 0;
      }
    }

    delayMicroseconds(100);
  }
}

void checkBoard() {
  int liftedSquare = -1;
  int newSquare = -1;

  for(int i = 0;i<64;i++) {
    if(board[i] == oldBoard[i])
      continue;

    if(oldBoard[i] == 1 && board[i] == 0) {
      liftedSquare = i;
      lifted = i;

      int r = i / 8;
      int c = i % 8;

      char letter = 'A' + c;
      int number = 8-r;

      ESPSerial.print("LIFTED: ");
      ESPSerial.print(letter);
      ESPSerial.println(number);
    }

    if(oldBoard[i] == 0 && board[i] == 1) {
      newSquare = i;
      placed = i;

      int r = i / 8;
      int c = i % 8;

      char letter = 'A' + c;
      int number = 8-r;

      ESPSerial.print("PLACED: ");
      ESPSerial.print(letter);
      ESPSerial.println(number);
    }
  }

  if(liftedSquare != -1 && newSquare != -1) {
    int r1 = liftedSquare / 8;
    int c1 = liftedSquare % 8;

    int r2 = newSquare / 8;
    int c2 = newSquare % 8;

    char f1 = 'A' + c1;
    char f2 = 'A' + c2;

    int n1 = 8-r1;
    int n2 = 8-r2;

    ESPSerial.print("MOVE: ");
    ESPSerial.print(f1);
    ESPSerial.print(n1);
    ESPSerial.print(" -> ");
    ESPSerial.print(f2);
    ESPSerial.println(n2);

    leds[r1][c1] = true;
    leds[r2][c2] = true;

    lifted = -1;
    placed = -1;
  }

  for(int i = 0;i<64;i++) {
    oldBoard[i] = board[i];
  }
}

void showLEDs() {
  if(millis() - lastLED < ledDelay)
    return;

  lastLED = millis();

  for(int row = 0; row<8; row++) {
    for(int i = 0;i<8;i++) {
      digitalWrite(ledRows[i], LOW);
      digitalWrite(ledCols[i], HIGH);
    }

    digitalWrite(ledRows[row], HIGH);

    for(int col = 0;col<8;col++) {
      if(leds[row][col])
        digitalWrite(ledCols[col], LOW);
    }

    delayMicroseconds(250);
  }
}

void loop() {
  scanHall();

  checkBoard();

  showLEDs();
}

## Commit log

2026-08-26 Enhance README with project details and specifications
    Expanded the README to include features, functionality, electronics details, CAD model information, and cost considerations for the chess board project.
2026-08-26 Revise README with feature updates and explanations
    Updated feature list and clarified how the board detects chess pieces and communicates with the chess engine.
2026-08-26 Update README.md to reflect project changes
    Removed references to Arduino Mega 2560, ESP32, and multiplexers from the features list. Added OLED screen to features and updated the cost section for clarity.
2026-08-29 Rename Chess Board V2.step to CAD/Chess Board V2.step
    [Chess Board V2.step]
2026-08-29 Rename Chess Pieces V2 - 4mm - Full.step to CAD/Chess Pieces V2 - 4mm - Full.step
    [Chess Pieces V2 - 4mm - Full.step]
2026-08-29 Rename Chess Board V7.kicad_pro to PCB/Chess Board V7.kicad_pro
2026-08-29 Rename Chess Board V7.kicad_pcb to PCB/Chess Board V7.kicad_pcb
    [Chess Board V7.kicad_pcb]
2026-08-29 Rename Chess Board V7.kicad_sch to PCB/Chess Board V7.kicad_sch
    [Chess Board V7.kicad_sch]
2026-08-29 Rename BOM - Electronic Chess Board.xlsx to BOM/BOM - Electronic Chess Board.xlsx
    [BOM - Electronic Chess Board.xlsx]
2026-08-29 Rename Chess Squares V4.step to CAD/Chess Squares V4.step
    [Chess Squares V4.step]
2026-08-29 Refine wording in README for clarity
    Updated descriptions for electronics and CAD model sections.
2026-08-29 Fix image tag formatting in README
    Updated image tag for the chess board design.
2026-08-29 Fix grammar and clarity in README section
    Corrected grammatical errors and improved clarity in the description of the chess board design.
2026-08-29 Rename BOM/BOM - Electronic Chess Board.xlsx to BOM - Electronic Chess Board.xlsx
    [BOM - Electronic Chess Board.xlsx]
2026-08-29 Update README with assembly details
    Added a note about using hot glue for assembly.
2026-08-29 Update glue description in README
2026-09-27 Update README with PCB and CAD model images
    Added images of PCB, CAD model, and chess board design.
